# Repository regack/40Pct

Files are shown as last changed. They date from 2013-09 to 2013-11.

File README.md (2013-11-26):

The SmallFry 40% Board
=====

## v0.8-v0.10
* I forget everything that I did, lots of little things
* fixed some unconnected pads (oops)
* cleaned up silkscreens again
* fixed diode pads to fit SOD-123 footprint
* fixed BOM info for components
* rounded PCB edges
* replaced slotted holes with... holes
* added Vcc and Gnd pins to LED expansion
* changed LED expansion pins to 2.54 pitch

## v0.7 - 2013.10.20
* cleaned up silkscreens
* moved 'ROW5' expansion to GPIO7 (still ATMEGA32U4 pin8/PB0)
* added notes
* cleaned up and removed extra libs/mods

## v0.6 - 2013.10.16
* pulled extra pin for ROW5 from ATMEGA pin 8/PB0
* changed drills for holes/slots to work with OSHpark 
* added GPIO4, GPIO5, GPIO6 connectors to ATMEGA pins 26/PD6, 22/PD5, 11/PB3
* ran row and GPIO to 1.27mm headers on right-side of board for interconnect (ribbon cable spacing)

## v0.5 - 2013.09.20
* added back missing slot on right side of board
* added LEDs for optional keys from v0.4
* generated pcb image * not sure why slots don't render properly
* removed bottom-of-board expansion pins

## v0.4 - 2013.09.19
* added optional 1.25+1.0 and 1.0+1.25 for right-shift/fn keys

## v0.3 - 2013.09.18
* based on the GH60 Rev B PCB
* SMT ATMEGA32U4 and other components on back of board
* Expansion ports on bottom and top row
* LEDs on ESC, 'CAPS', and WASD Cluster
* Other LEDs in matrix with expansion points on top row

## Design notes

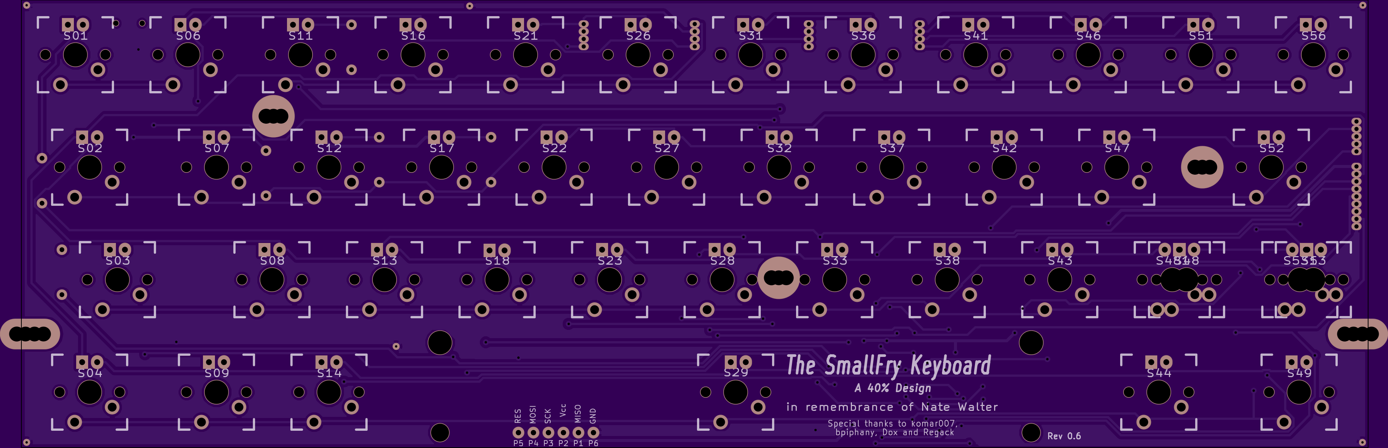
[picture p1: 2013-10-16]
pcb.png

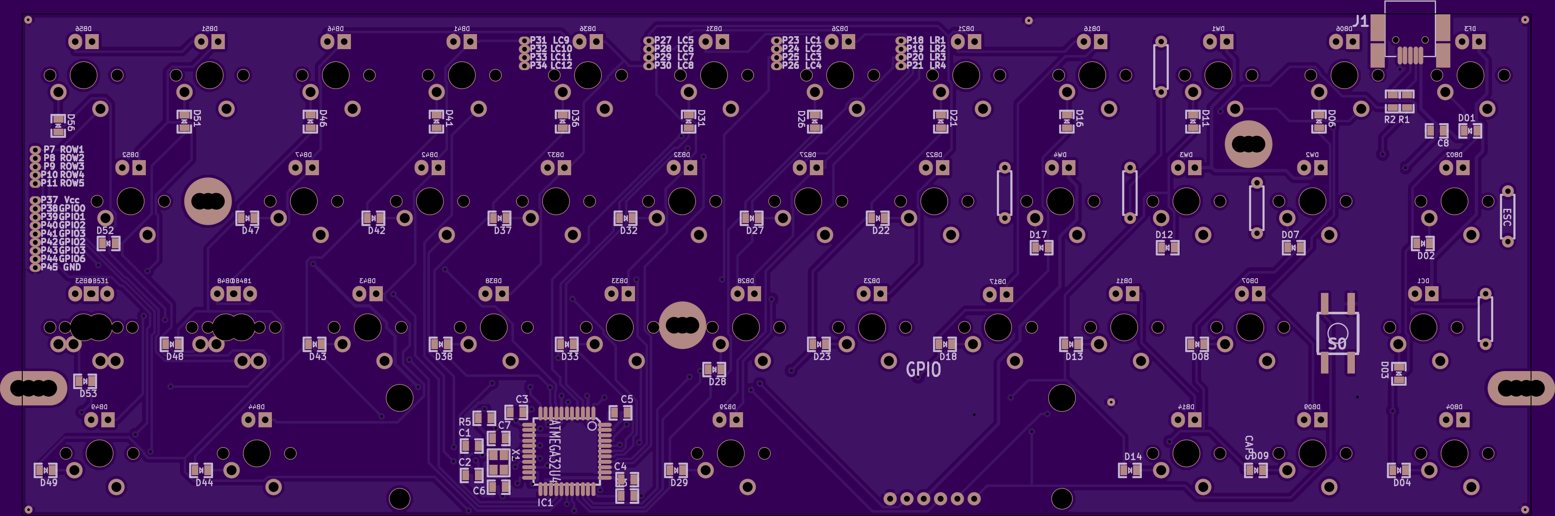
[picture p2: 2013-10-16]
pcb_back.png

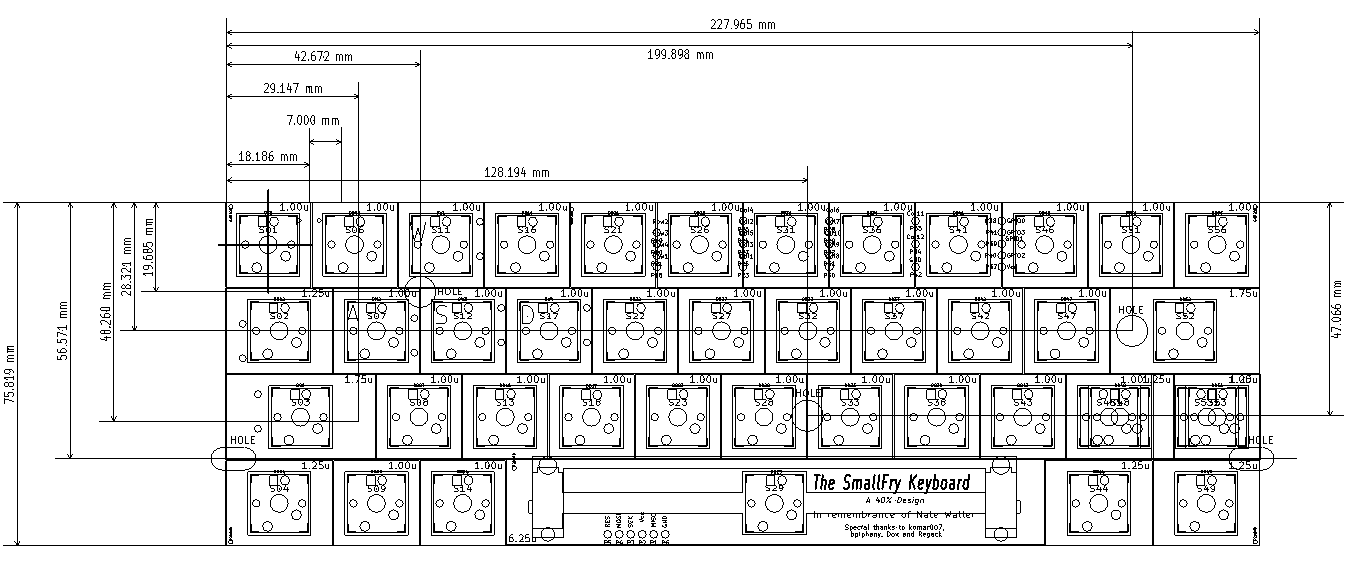
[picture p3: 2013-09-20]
dimensions.png

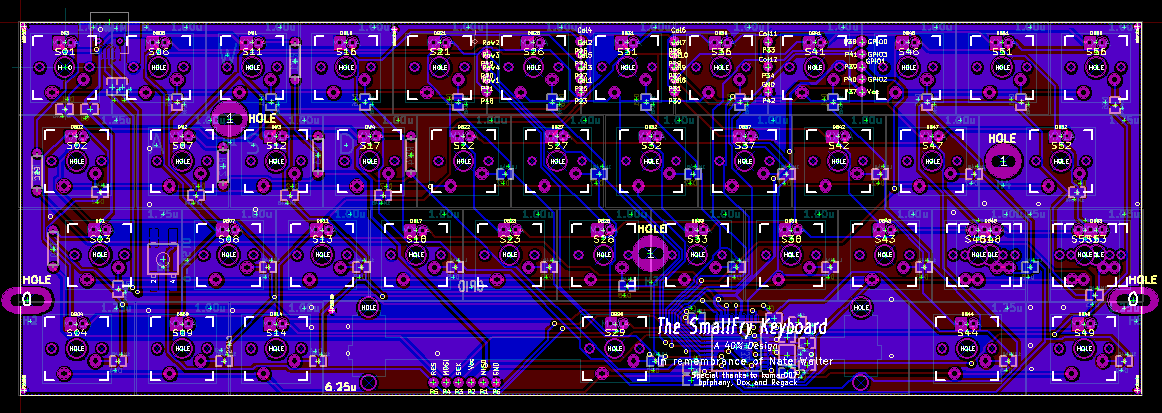
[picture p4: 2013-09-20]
board.png

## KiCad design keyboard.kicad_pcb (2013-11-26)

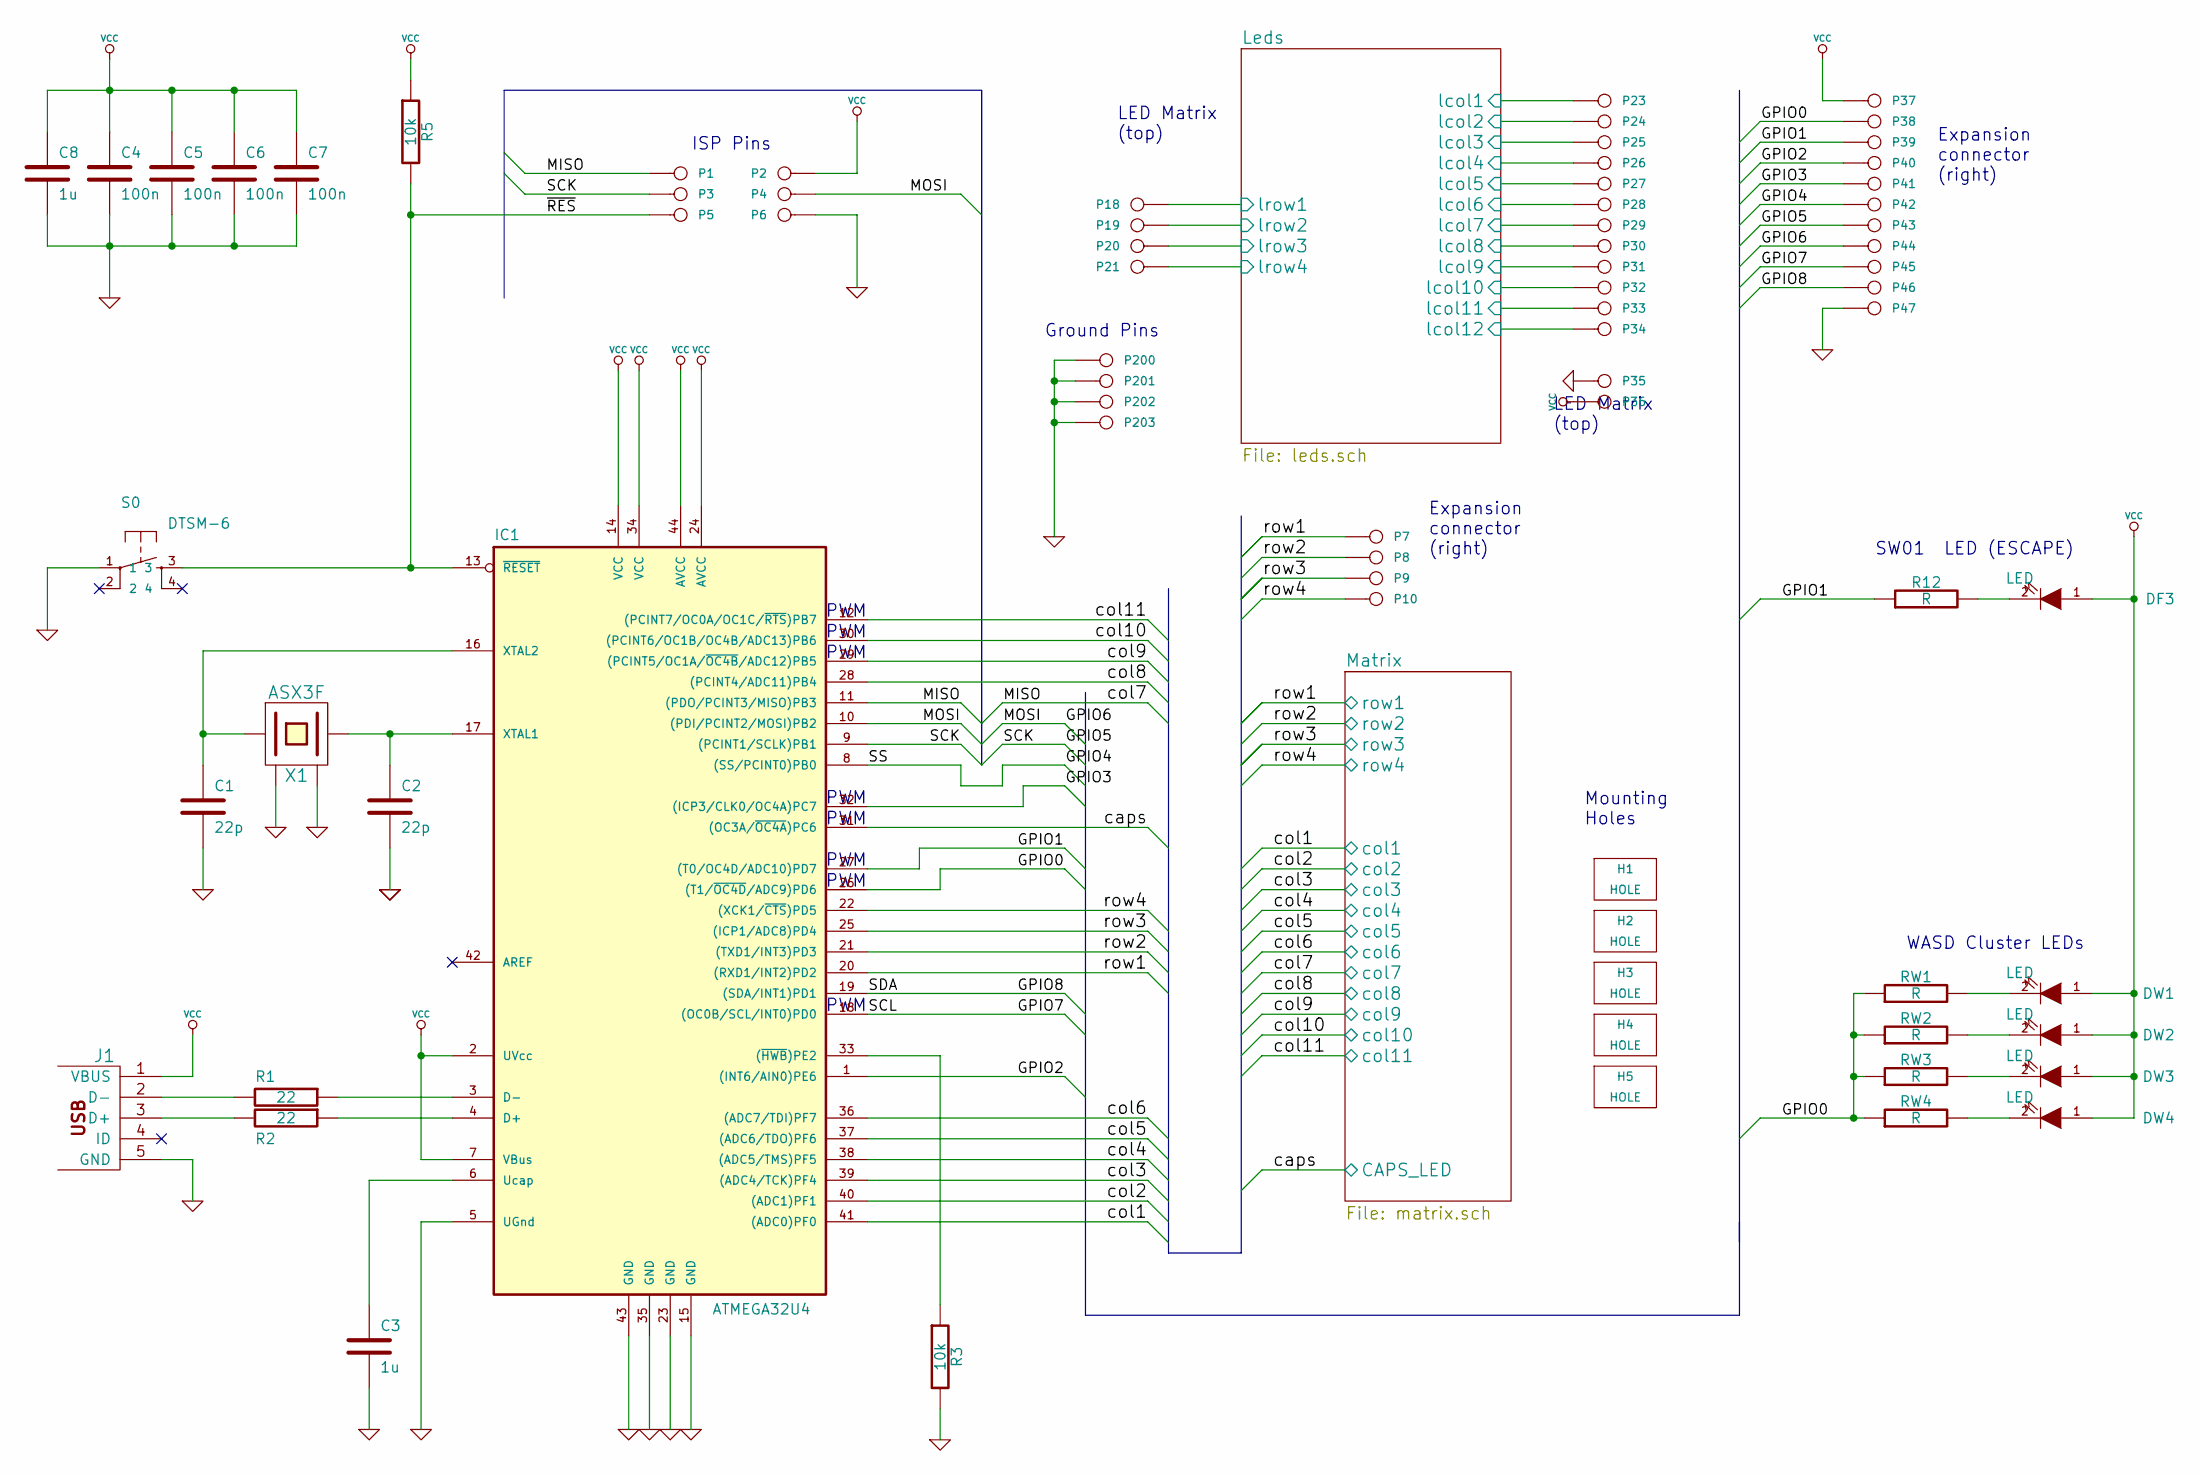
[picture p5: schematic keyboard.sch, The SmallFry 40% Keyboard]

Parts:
C1, C2: 22p
C3, C8: 1u
C4, C5, C6, C7: 100n
DF3: LED
DW1, DW2, DW3, DW4: LED
H1, H2, H3, H4, H5: HOLE
IC1: ATMEGA32U4; TQFP44
J1: MINI
P1: MISO
P2, P37: Vcc
P3: SCK
P4: MOSI
P5: RES
P6, P47, P200, P201, P202, P203: GND
P7: ROW1
P8: ROW2
P9: ROW3
P10: ROW4
P18: LR1
P19: LR2
P20: LR3
P21: LR4
P23: LC1
P24: LC2
P25: LC3
P26: LC4
P27: LC5
P28: LC6
P29: LC7
P30: LC8
P31: LC9
P32: LC10
P33: LC11
P34: LC12
P35: LGND
P36: LVcc
P38: GPIO0
P39: GPIO1
P40: GPIO2
P41: GPIO3
P42: GPIO4(SS)
P43: GPIO5(SCK)
P44: GPIO6(MOSI)
P45: GPIO7(SCL)
P46: GPIO8(SDA)
R1, R2: 22
R3, R5: 10k
R12: R
RW1, RW2, RW3, RW4: R
S0: DTSM-6; switch-tact-DTSM-6
X1: ASX3F

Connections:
/GPIO0: IC1.26 ((T1/~OC4D~/ADC9)PD6), P38.1, RW1.1, RW2.1, RW3.1, RW4.1
/GPIO1: IC1.27 ((T0/OC4D/ADC10)PD7), P39.1, R12.1
/GPIO2: IC1.1 ((INT6/AIN0)PE6), P40.1
/GPIO3: IC1.32 ((ICP3/CLK0/OC4A)PC7), P41.1
/GPIO4: IC1.8 ((SS/PCINT0)PB0), P42.1
/GPIO5: IC1.9 ((PCINT1/SCLK)PB1), P3.1, P43.1
/GPIO6: IC1.10 ((PDI/PCINT2/MOSI)PB2), P4.1, P44.1
/GPIO7: IC1.18 ((OC0B/SCL/INT0)PD0), P45.1
/GPIO8: IC1.19 ((SDA/INT1)PD1), P46.1
/Leds/lcol1: P23.1; also elsewhere on the board
/Leds/lcol2: P24.1; also elsewhere on the board
/Leds/lcol3: P25.1; also elsewhere on the board
/Leds/lcol4: P26.1; also elsewhere on the board
/Leds/lcol5: P27.1; also elsewhere on the board
/Leds/lcol6: P28.1; also elsewhere on the board
/Leds/lcol7: P29.1; also elsewhere on the board
/Leds/lcol8: P30.1; also elsewhere on the board
/Leds/lcol9: P31.1; also elsewhere on the board
/Leds/lcol10: P32.1; also elsewhere on the board
/Leds/lcol11: P33.1; also elsewhere on the board
/Leds/lcol12: P34.1; also elsewhere on the board
/Leds/lrow1: P18.1; also elsewhere on the board
/Leds/lrow2: P19.1; also elsewhere on the board
/Leds/lrow3: P20.1; also elsewhere on the board
/Leds/lrow4: P21.1; also elsewhere on the board
/Matrix/CAPS_LED: IC1.31 ((OC3A/~OC4A~)PC6); also elsewhere on the board
/Matrix/col1: IC1.41 ((ADC0)PF0); also elsewhere on the board
/Matrix/col2: IC1.40 ((ADC1)PF1); also elsewhere on the board
/Matrix/col3: IC1.39 ((ADC4/TCK)PF4); also elsewhere on the board
/Matrix/col4: IC1.38 ((ADC5/TMS)PF5); also elsewhere on the board
/Matrix/col5: IC1.37 ((ADC6/TDO)PF6); also elsewhere on the board
/Matrix/col6: IC1.36 ((ADC7/TDI)PF7); also elsewhere on the board
/Matrix/col7: IC1.11 ((PDO/PCINT3/MISO)PB3), P1.1; also elsewhere on the board
/Matrix/col8: IC1.28 ((PCINT4/ADC11)PB4); also elsewhere on the board
/Matrix/col9: IC1.29 ((PCINT5/OC1A/~OC4B~/ADC12)PB5); also elsewhere on the board
/Matrix/col10: IC1.30 ((PCINT6/OC1B/OC4B/ADC13)PB6); also elsewhere on the board
/Matrix/col11: IC1.12 ((PCINT7/OC0A/OC1C/~RTS~)PB7); also elsewhere on the board
/Matrix/row1: IC1.20 ((RXD1/INT2)PD2), P7.1; also elsewhere on the board
/Matrix/row2: IC1.21 ((TXD1/INT3)PD3), P8.1; also elsewhere on the board
/Matrix/row3: IC1.25 ((ICP1/ADC8)PD4), P9.1; also elsewhere on the board
/Matrix/row4: IC1.22 ((XCK1/~CTS~)PD5), P10.1; also elsewhere on the board
/~RES~: IC1.13 (~RESET~), P5.1, R5.2, S0.3
GND: C1.2, C2.2, C3.2, C4.2, C5.2, C6.2, C7.2, C8.2, IC1.5 (UGnd), IC1.15 (GND), IC1.23 (GND), IC1.35 (GND), IC1.43 (GND), J1.5 (GND), P6.1, P35.1, P47.1, P200.1, P201.1, P202.1, P203.1, R3.2, S0.1, X1.2 (GND), X1.4 (GND)
unnamed: C2.1, IC1.17 (XTAL1), X1.3 (2)
unnamed: C1.1, IC1.16 (XTAL2), X1.1
unnamed: J1.2 (D-), R1.2
unnamed: J1.3 (D+), R2.2
unnamed: C3.1, IC1.6 (Ucap)
unnamed: IC1.4 (D+), R2.1
unnamed: IC1.3 (D-), R1.1
unnamed: DW1.2 (K), RW1.2
unnamed: DW2.2 (K), RW2.2
unnamed: DW3.2 (K), RW3.2
unnamed: IC1.33 ((~HWB~)PE2), R3.1
unnamed: DF3.2 (K), R12.2
unnamed: DW4.2 (K), RW4.2
VCC: C4.1, C5.1, C6.1, C7.1, C8.1, DF3.1 (A), DW1.1 (A), DW2.1 (A), DW3.1 (A), DW4.1 (A), IC1.2 (UVcc), IC1.7 (VBus), IC1.14 (VCC), IC1.24 (AVCC), IC1.34 (VCC), IC1.44 (AVCC), J1.1 (VBUS), P2.1, P36.1, P37.1, R5.1; also elsewhere on the board

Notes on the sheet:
Expansion connector (right)
PWM
LED Matrix (top)
Mounting Holes
Ground Pins
ISP Pins
WASD Cluster LEDs
SW01 LED (ESCAPE)

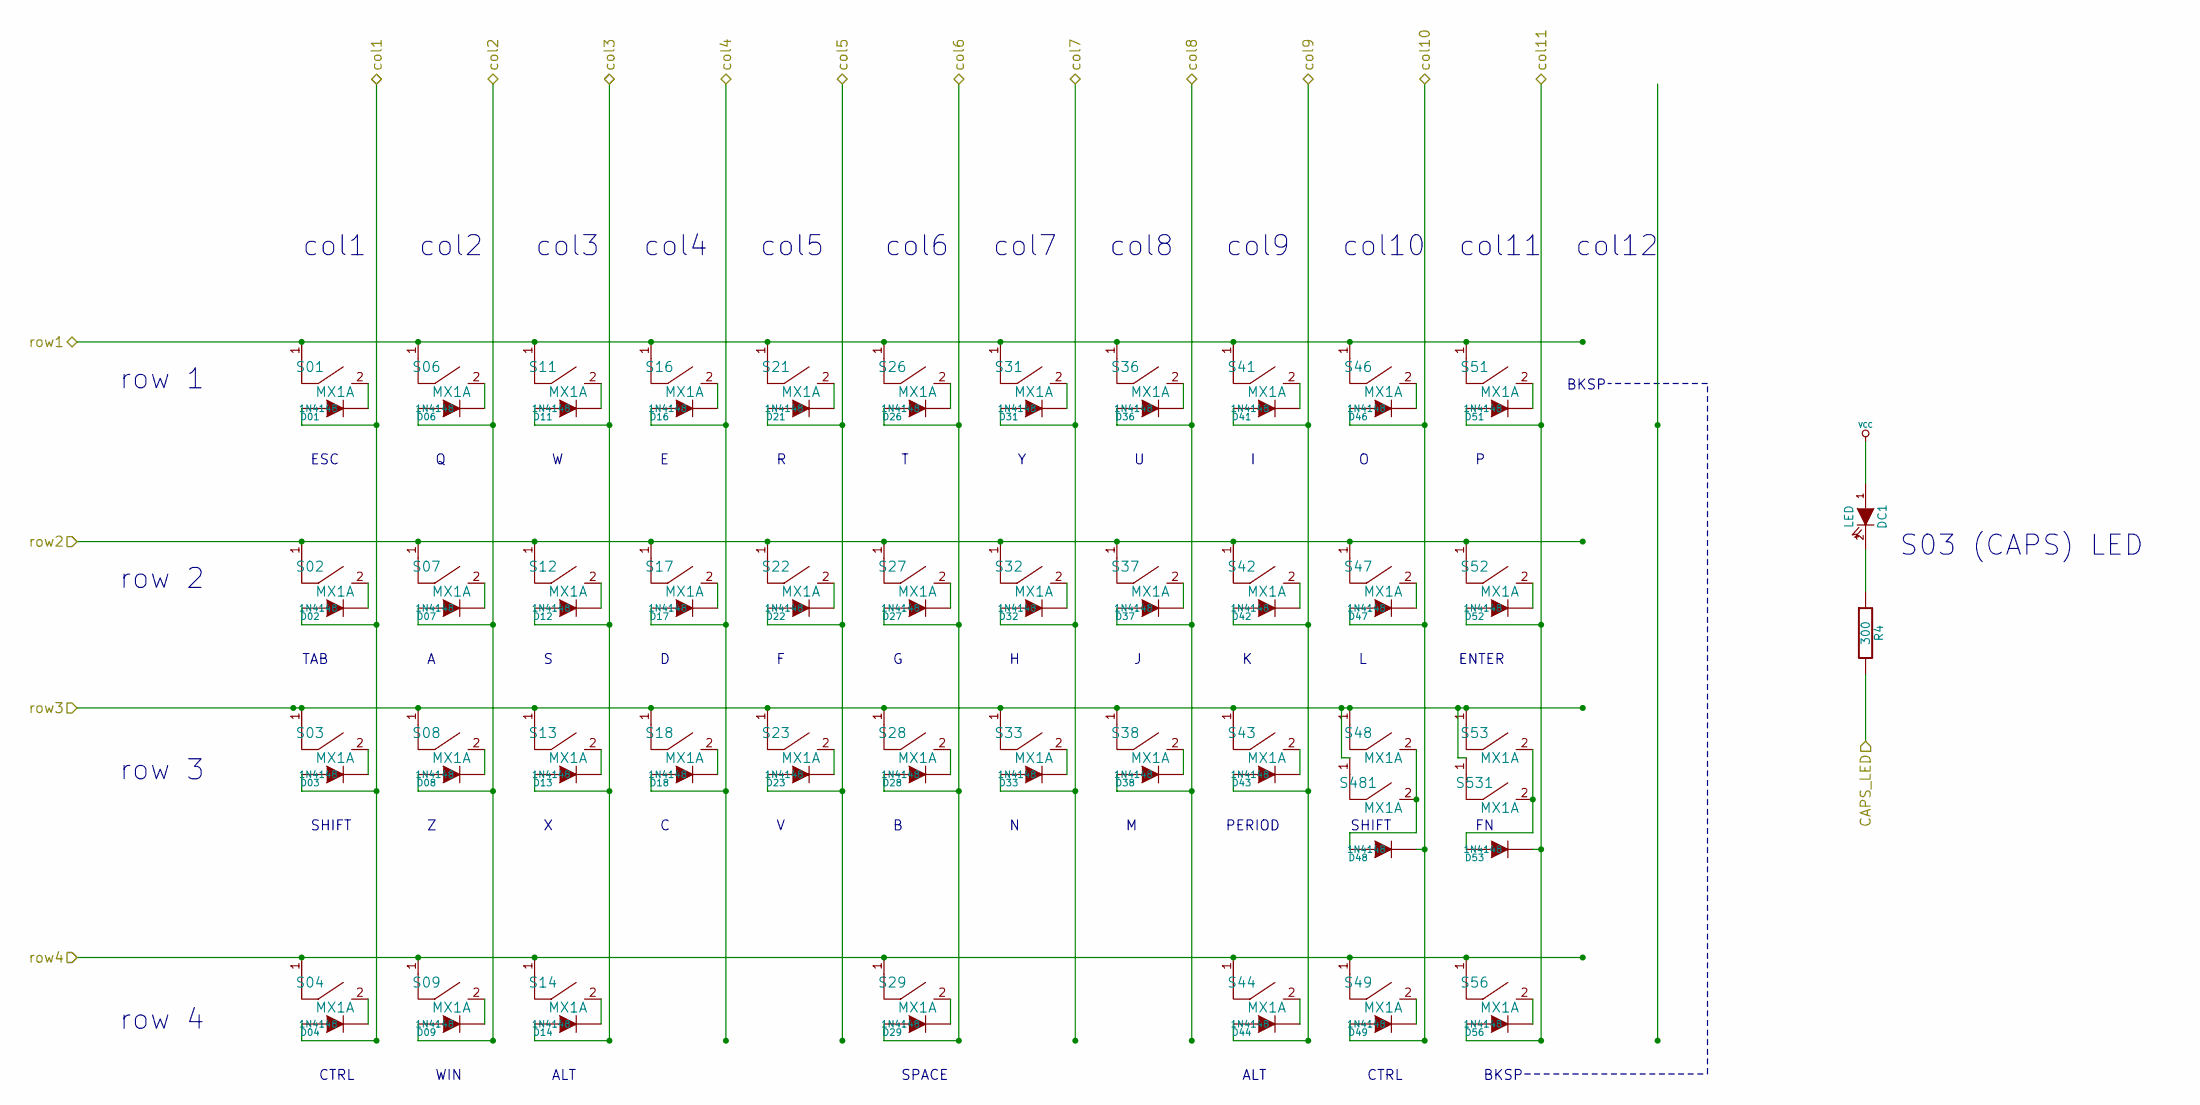
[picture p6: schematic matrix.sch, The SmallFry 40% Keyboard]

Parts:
D01, D02, D03, D04, D06, D07, D08, D09, D11, D12, D13, D14, D16, D17, D18, D21, D22, D23, D26, D27, D28, D29, D31, D32, D33, D36, D37, D38, D41, D42, D43, D44, D46, D47, D48, D49, D51, D52, D53, D56: 1N4148
DC1: LED
R4: 300
S01, S02, S03, S04, S06, S07, S08, S09, S11, S12, S13, S14, S16, S17, S18, S21, S22, S23, S26, S27, S28, S29, S31, S32, S33, S36, S37, S38, S41, S42, S43, S44, S46, S47, S48, S49, S51, S52, S53, S56, S481, S531: MX1A

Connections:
/Matrix/CAPS_LED: R4.2; also elsewhere on the board
/Matrix/col1: D01.1 (A), D02.1 (A), D03.1 (A), D04.1 (A); also elsewhere on the board
/Matrix/col2: D06.1 (A), D07.1 (A), D08.1 (A), D09.1 (A); also elsewhere on the board
/Matrix/col3: D11.1 (A), D12.1 (A), D13.1 (A), D14.1 (A); also elsewhere on the board
/Matrix/col4: D16.1 (A), D17.1 (A), D18.1 (A); also elsewhere on the board
/Matrix/col5: D21.1 (A), D22.1 (A), D23.1 (A); also elsewhere on the board
/Matrix/col6: D26.1 (A), D27.1 (A), D28.1 (A), D29.1 (A); also elsewhere on the board
/Matrix/col7: D31.1 (A), D32.1 (A), D33.1 (A); also elsewhere on the board
/Matrix/col8: D36.1 (A), D37.1 (A), D38.1 (A); also elsewhere on the board
/Matrix/col9: D41.1 (A), D42.1 (A), D43.1 (A), D44.1 (A); also elsewhere on the board
/Matrix/col10: D46.1 (A), D47.1 (A), D48.2 (K), D49.1 (A); also elsewhere on the board
/Matrix/col11: D51.1 (A), D52.1 (A), D53.2 (K), D56.1 (A); also elsewhere on the board
/Matrix/row1: S01.1, S06.1, S11.1, S16.1, S21.1, S26.1, S31.1, S36.1, S41.1, S46.1, S51.1; also elsewhere on the board
/Matrix/row2: S02.1, S07.1, S12.1, S17.1, S22.1, S27.1, S32.1, S37.1, S42.1, S47.1, S52.1; also elsewhere on the board
/Matrix/row3: S03.1, S08.1, S13.1, S18.1, S23.1, S28.1, S33.1, S38.1, S43.1, S48.1, S53.1, S481.1, S531.1; also elsewhere on the board
/Matrix/row4: S04.1, S09.1, S14.1, S29.1, S44.1, S49.1, S56.1; also elsewhere on the board
unnamed: D23.2 (K), S23.2
unnamed: D01.2 (K), S01.2
unnamed: D33.2 (K), S33.2
unnamed: D32.2 (K), S32.2
unnamed: D31.2 (K), S31.2
unnamed: D21.2 (K), S21.2
unnamed: D22.2 (K), S22.2
unnamed: D11.2 (K), S11.2
unnamed: D47.2 (K), S47.2
unnamed: D46.2 (K), S46.2
unnamed: D42.2 (K), S42.2
unnamed: D43.2 (K), S43.2
unnamed: D38.2 (K), S38.2
unnamed: D37.2 (K), S37.2
unnamed: D41.2 (K), S41.2
unnamed: D36.2 (K), S36.2
unnamed: D12.2 (K), S12.2
unnamed: D26.2 (K), S26.2
unnamed: D14.2 (K), S14.2
unnamed: D09.2 (K), S09.2
unnamed: D13.2 (K), S13.2
unnamed: D08.2 (K), S08.2
unnamed: D07.2 (K), S07.2
unnamed: D02.2 (K), S02.2
unnamed: D17.2 (K), S17.2
unnamed: D18.2 (K), S18.2
unnamed: D16.2 (K), S16.2
unnamed: D29.2 (K), S29.2
unnamed: D28.2 (K), S28.2
unnamed: D27.2 (K), S27.2
unnamed: D03.2 (K), S03.2
unnamed: D48.1 (A), S48.2, S481.2
unnamed: D53.1 (A), S53.2, S531.2
unnamed: D04.2 (K), S04.2
unnamed: D56.2 (K), S56.2
unnamed: D49.2 (K), S49.2
unnamed: D44.2 (K), S44.2
unnamed: D52.2 (K), S52.2
unnamed: D51.2 (K), S51.2
unnamed: DC1.2 (K), R4.1
unnamed: D06.2 (K), S06.2
VCC: DC1.1 (A); also elsewhere on the board

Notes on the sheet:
row 1
row 2
row 3
row 4
col1
col2
col3
col4
col5
col6
col7
col9
col10
col11
col12
col8
ESC
TAB
BKSP
SHIFT
ENTER
CTRL
WIN
ALT
PERIOD
SPACE
S03 (CAPS) LED

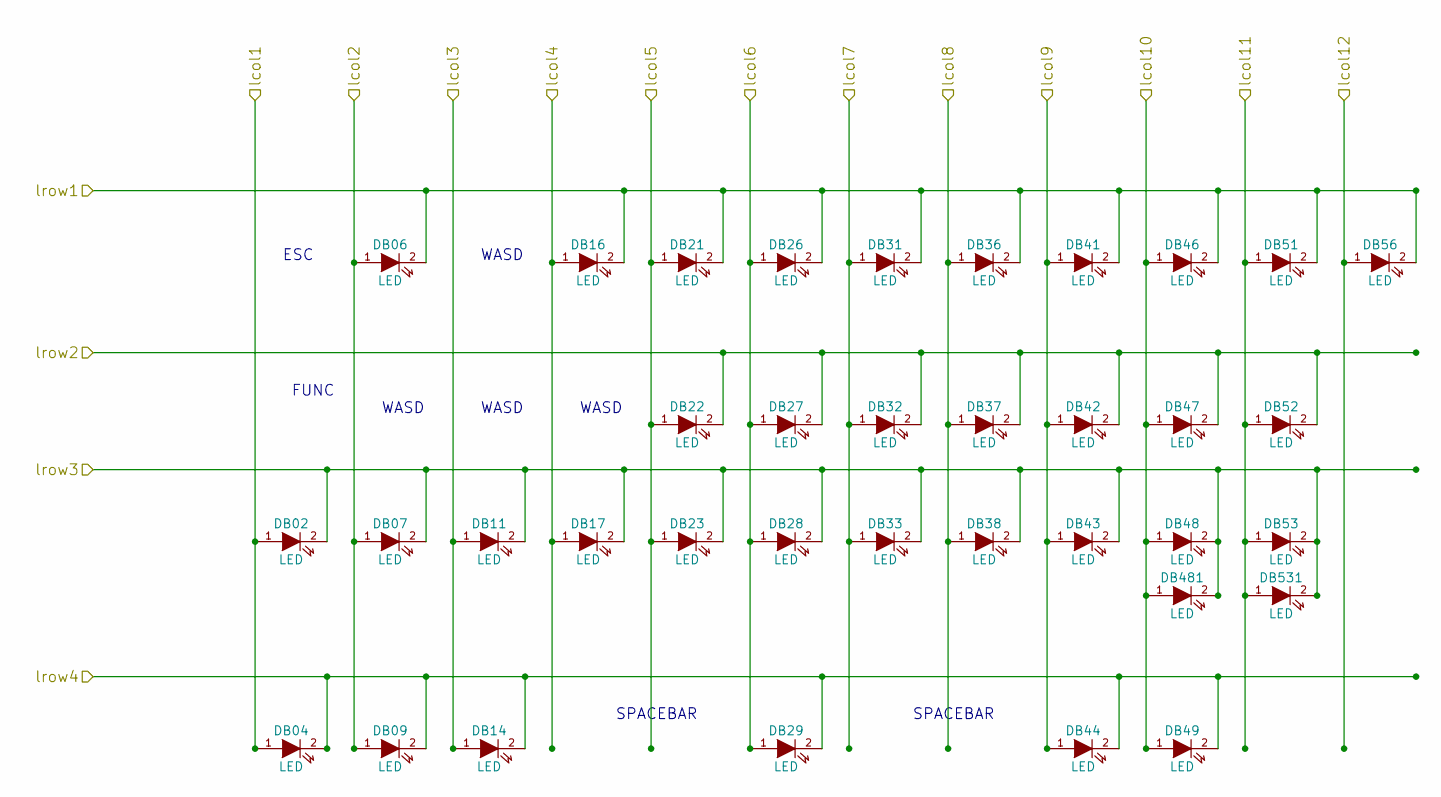
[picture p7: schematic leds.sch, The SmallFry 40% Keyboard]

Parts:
DB02, DB04, DB06, DB07, DB09, DB11, DB14, DB16, DB17, DB21, DB22, DB23, DB26, DB27, DB28, DB29, DB31, DB32, DB33, DB36, DB37, DB38, DB41, DB42, DB43, DB44, DB46, DB47, DB48, DB49, DB51, DB52, DB53, DB56, DB481, DB531: LED

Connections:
/Leds/lcol1: DB02.1 (A), DB04.1 (A); also elsewhere on the board
/Leds/lcol2: DB06.1 (A), DB07.1 (A), DB09.1 (A); also elsewhere on the board
/Leds/lcol3: DB11.1 (A), DB14.1 (A); also elsewhere on the board
/Leds/lcol4: DB16.1 (A), DB17.1 (A); also elsewhere on the board
/Leds/lcol5: DB21.1 (A), DB22.1 (A), DB23.1 (A); also elsewhere on the board
/Leds/lcol6: DB26.1 (A), DB27.1 (A), DB28.1 (A), DB29.1 (A); also elsewhere on the board
/Leds/lcol7: DB31.1 (A), DB32.1 (A), DB33.1 (A); also elsewhere on the board
/Leds/lcol8: DB36.1 (A), DB37.1 (A), DB38.1 (A); also elsewhere on the board
/Leds/lcol9: DB41.1 (A), DB42.1 (A), DB43.1 (A), DB44.1 (A); also elsewhere on the board
/Leds/lcol10: DB46.1 (A), DB47.1 (A), DB48.1 (A), DB49.1 (A), DB481.1 (A); also elsewhere on the board
/Leds/lcol11: DB51.1 (A), DB52.1 (A), DB53.1 (A), DB531.1 (A); also elsewhere on the board
/Leds/lcol12: DB56.1 (A); also elsewhere on the board
/Leds/lrow1: DB06.2 (K), DB16.2 (K), DB21.2 (K), DB26.2 (K), DB31.2 (K), DB36.2 (K), DB41.2 (K), DB46.2 (K), DB51.2 (K), DB56.2 (K); also elsewhere on the board
/Leds/lrow2: DB22.2 (K), DB27.2 (K), DB32.2 (K), DB37.2 (K), DB42.2 (K), DB47.2 (K), DB52.2 (K); also elsewhere on the board
/Leds/lrow3: DB02.2 (K), DB07.2 (K), DB11.2 (K), DB17.2 (K), DB23.2 (K), DB28.2 (K), DB33.2 (K), DB38.2 (K), DB43.2 (K), DB48.2 (K), DB53.2 (K), DB481.2 (K), DB531.2 (K); also elsewhere on the board
/Leds/lrow4: DB04.2 (K), DB09.2 (K), DB14.2 (K), DB29.2 (K), DB44.2 (K), DB49.2 (K); also elsewhere on the board

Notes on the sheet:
WASD
FUNC
ESC
SPACEBAR

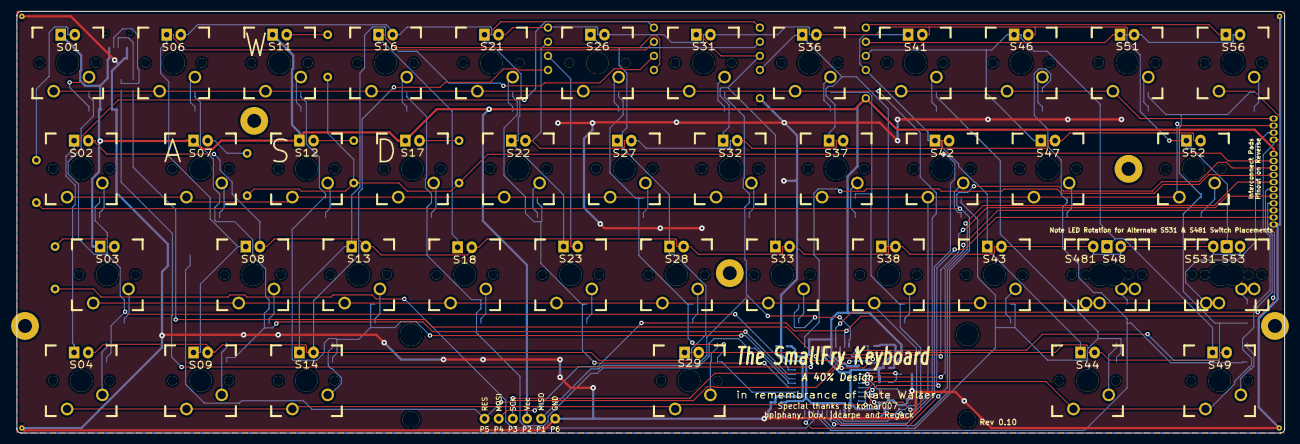
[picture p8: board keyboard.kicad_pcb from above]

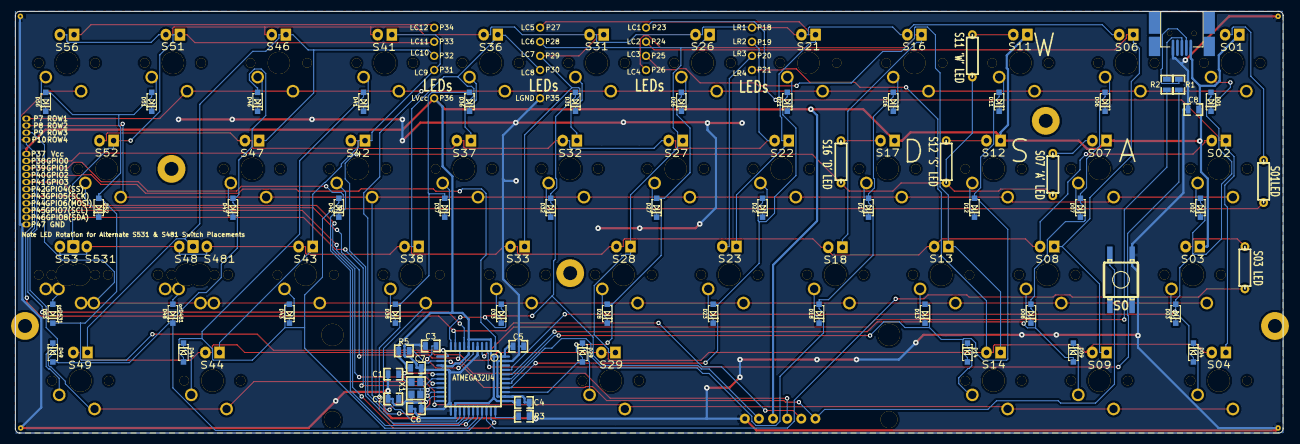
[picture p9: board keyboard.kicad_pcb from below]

Board: 2 copper layers, 228.0 x 75.8 mm, 194 parts (97 on the bottom side), 98 nets.
